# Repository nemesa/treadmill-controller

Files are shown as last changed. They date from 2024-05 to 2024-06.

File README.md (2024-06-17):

# treadmill-controller

## Try it in browser with a simulated arduino!
[Wokwi project](https://wokwi.com/projects/400015246220451841)

## Why is this project created?

I had two problems with my tredmill which I solved with a hardware button hack and an arudino uno.

[youtube video - during operation ](https://www.youtube.com/watch?v=EVUXpr3S0uo)

- Problem 1:
Speed setup

On my tredmill you can set an instant speed to 3, 6, 10, 16 Km/h and you can increase or decrase the speed by 0.1 Km/h, which sounds good until you want to run with the speed of 7.5 Km/h.  

In this case you have to set yout speed to 6 Km/h then increase your speed with 0.1 Km/h **15 times**!  
Like wise if you want to set speed to 4 km/h then you set your speed to 3 Km/h then increase your speed with 0.1 Km/h 10 times.
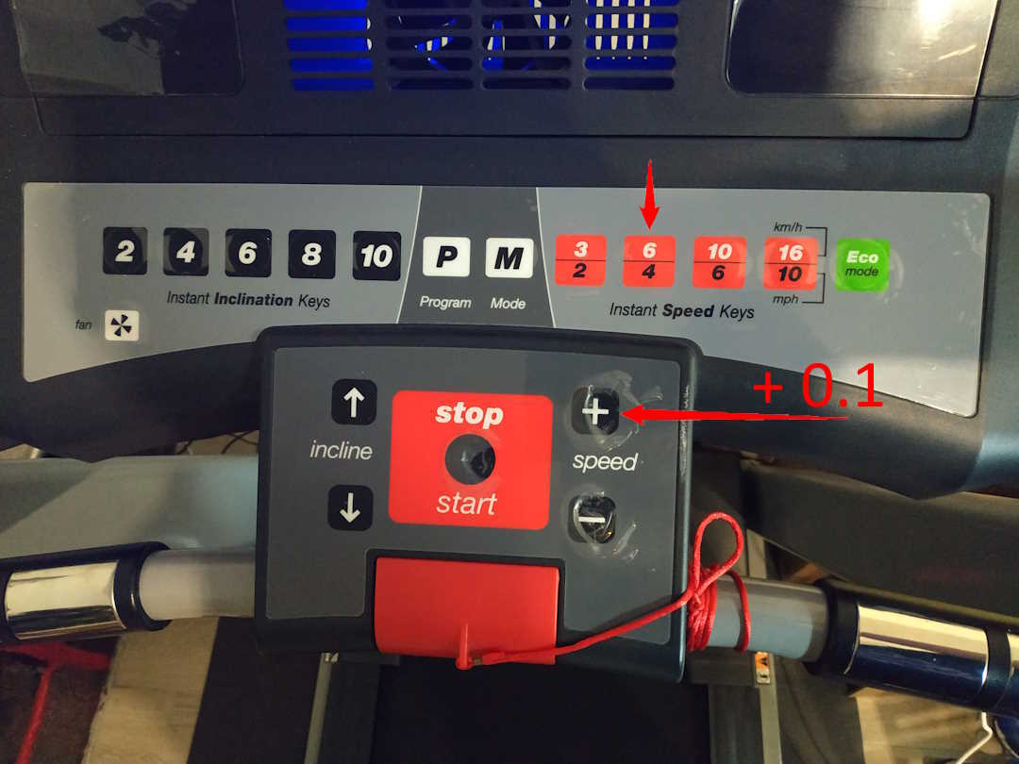
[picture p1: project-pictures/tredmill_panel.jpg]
tredmill_panel


- Problem 2:
Workout timeings

I usualy do intervall based trainings for example this one which trains you for a 5Km run race if you are newer did any runing before:

| week | workout code | workout day 1 |workout day 2 |workout day 3 |
|---|---|---|---|---|
| 1-2 | 2W&#124;[5&#124;1R&#124;2W] | 2 min walk -> 5X (1 min run -> 2 min walk) | same | rest |
| 3-4 | 2W&#124;[8&#124;1R&#124;1W]&#124;1W | 2walk -> 8X (1run, 1walk) -> 1walk | same | rest |
| 5 | 3W&#124;[4&#124;2R&#124;2W]&#124;1W | 3walk -> 4X (2run, 2walk) -> 1walk| same | same |
| 6 | 3W&#124;[5&#124;2R&#124;1W]&#124;1W | 3walk -> 5X (2run, 1walk) -> 1walk|rest | same |
| 7 | 4W&#124;[2&#124;2R&#124;1W&#124;3R&#124;2W] | 4walk -> 2X (2run, 1walk, 3run, 2walk)|rest | 45 min other workout |
| 8 | 4W&#124;[3&#124;3R&#124;2W]&#124;3W | 4walk -> 3X (3run, 2walk) -> 3walk| same | 45 min other workout |
| 9 | 4W&#124;[4&#124;3R&#124;1W]&#124;3W | 4walk -> 4X (3run, 2walk) -> 2walk| rest | rest |
| 10 | 5W&#124;[3&#124;4R&#124;2W]&#124;2W | 5walk -> 3X (4run, 2walk) -> 2walk| same | same |
| 11 | 5W&#124;[2&#124;5R&#124;2W]&#124;3R&#124;4W | 5walk -> 2X (5run, 2walk) -> 3run -> 4walk|same | 50 min other workout |
| 12 | 5W&#124;[2&#124;7R&#124;2W]&#124;2W | 5walk -> 2X (7run, 2walk) -> 2walk| rest | rest |
| 13 | 5W&#124;10R&#124;2W&#124;5R&#124;5W | 5walk -> 10run -> 2walk -> 5run -> 5walk|same | same |
| 14 | 5W&#124;15R&#124;6W | 5walk -> 15run -> 6walk | same | rest |
| 15 | 5W&#124;[4&#124;5R&#124;1W]&#124;2W | 5walk -> 4X (5run, 1walk) -> 2walk| rest | rest |
| 16 | 5W&#124;[3&#124;6R&#124;1W]&#124;4W | 5walk -> 3X (6run, 1walk) -> 4walk| same | same |
| 17 | 5W&#124;[3&#124;7R&#124;2W]&#124;4W | 5walk -> 3X (7run, 2walk) -> 4walk| same | same |
| 18 | 5W&#124;10R&#124;2W&#124;12R&#124;4W | 5walk -> 10run -> 2walk -> 12run -> 4walk | rest | rest |
| 19 | 5W&#124;[3&#124;9R&#124;1W] | 5walk -> 3X (9run, 1walk)| same | 60 min other workout |
| 20 | 5W&#124;15R&#124;2W&#124;[2&#124;5R&#124;2W] | 5walk -> 15run -> 2walk -> 2X (5run, 2walk)| same | same |
| 21 | 5W&#124;[3&#124;9R&#124;2W] | 5walk -> 3X (9run, 2walk)| same | same |
| 22 | 5W&#124;[3&#124;12R&#124;2W]&#124;4R&#124;4W | 5walk -> 3X (12run, 2walk) -> 4run -> 4walk| rest | 30 min other workout |
| 23 | 5W&#124;[3&#124;14R&#124;2W]&#124;2W | 5walk -> 3X (14run, 2walk) -> 2walk| rest | rest |
| 24 | 5W&#124;18R&#124;2W&#124;10R&#124;4W | 5walk -> 18run -> 2walk -> 10run -> 4walk  |same | 5 km race day |

So if we take week 3 which is a:  
2 min walk then 8X (1 min run then 1 min walk) then 1 min walk  
then would need to keep track of time and change between run and walk speed **18 times** and if you keep in mind the button press problem if you are an unfortunate invidual who walks at a speed of 4.5 Km/h and runs ant 7.5 Km/h then you will press buttons a woppin **15 x 18 = 270** times.  
This problem was screeaming for automation.

## Hardware button hack

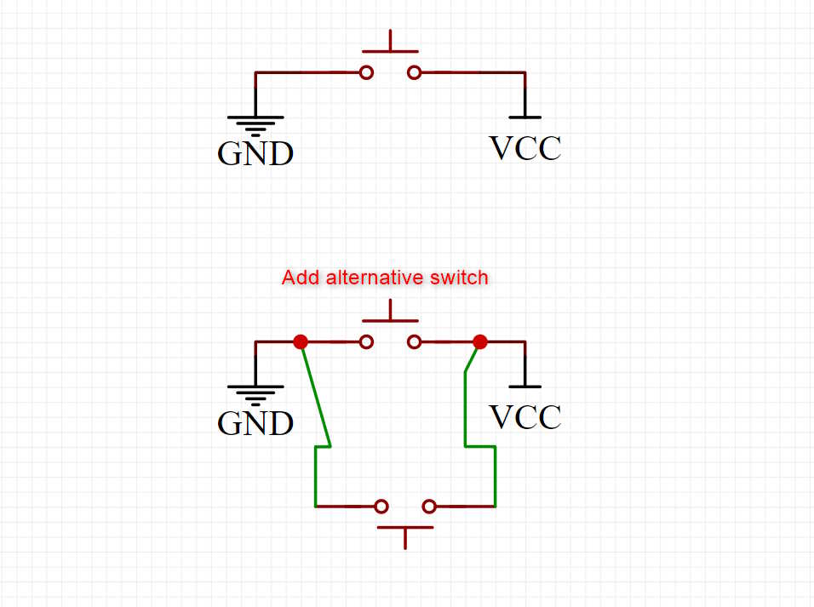
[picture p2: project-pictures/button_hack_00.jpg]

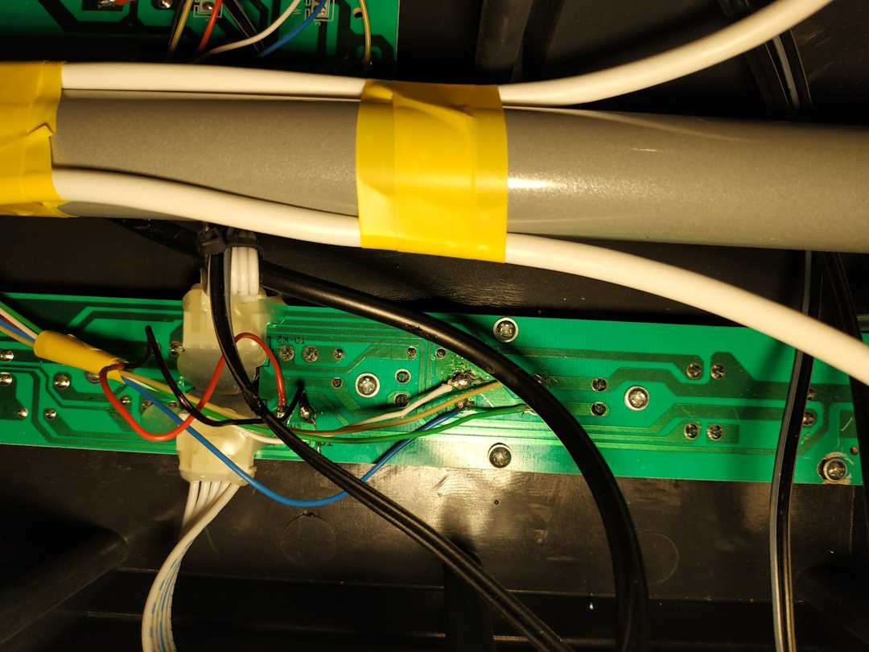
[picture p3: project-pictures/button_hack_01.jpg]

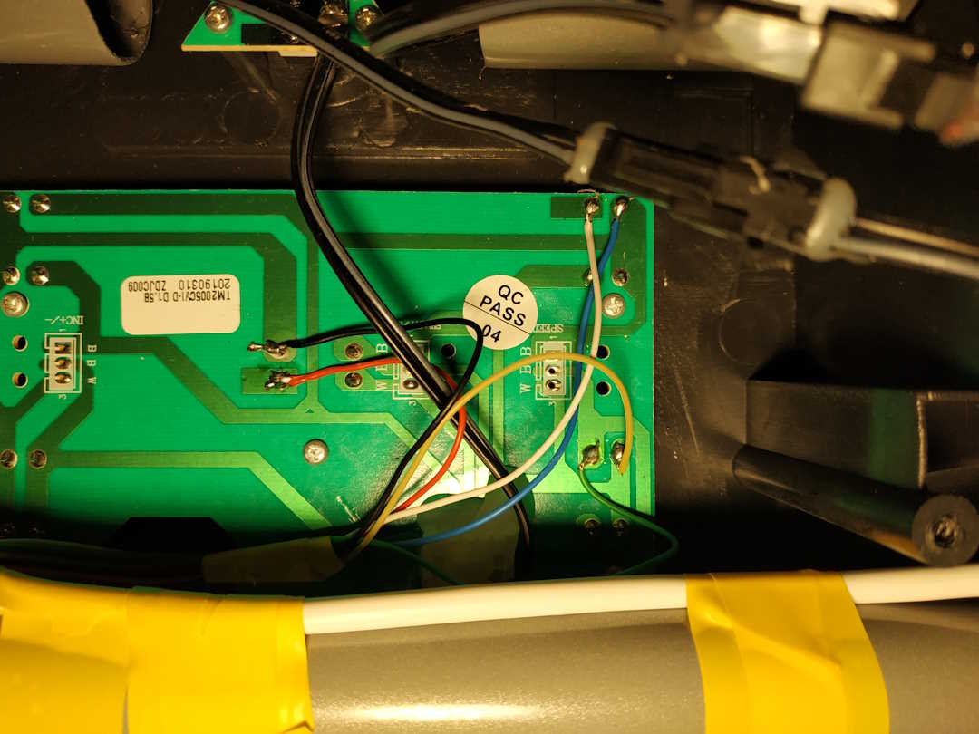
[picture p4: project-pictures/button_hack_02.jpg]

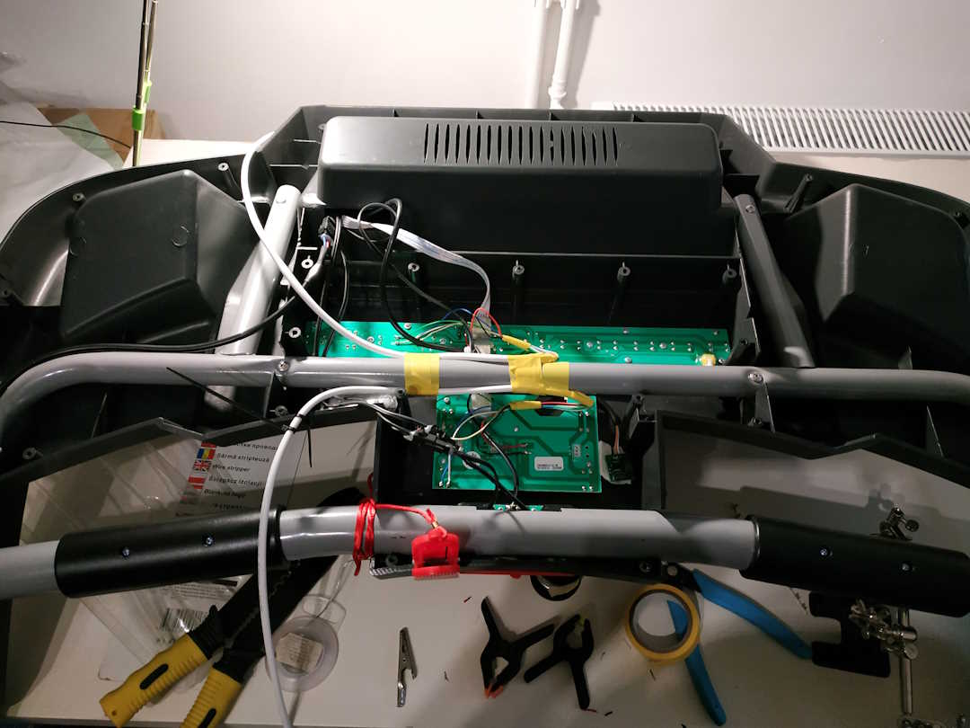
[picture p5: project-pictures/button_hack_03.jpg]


## Prototype

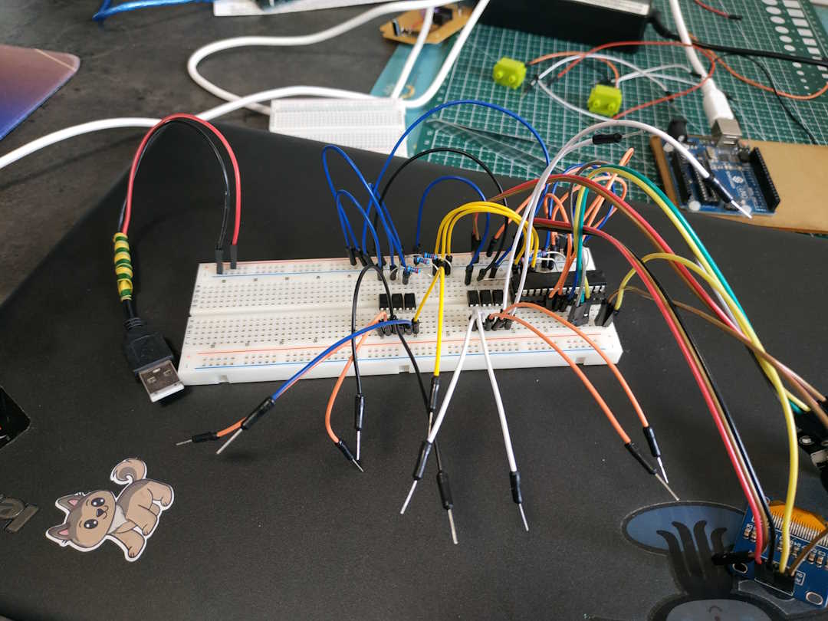
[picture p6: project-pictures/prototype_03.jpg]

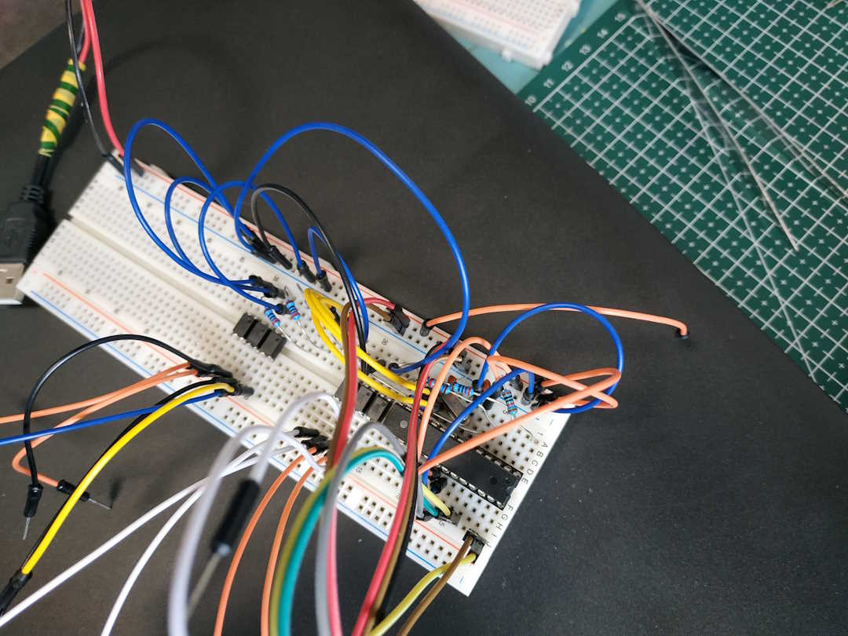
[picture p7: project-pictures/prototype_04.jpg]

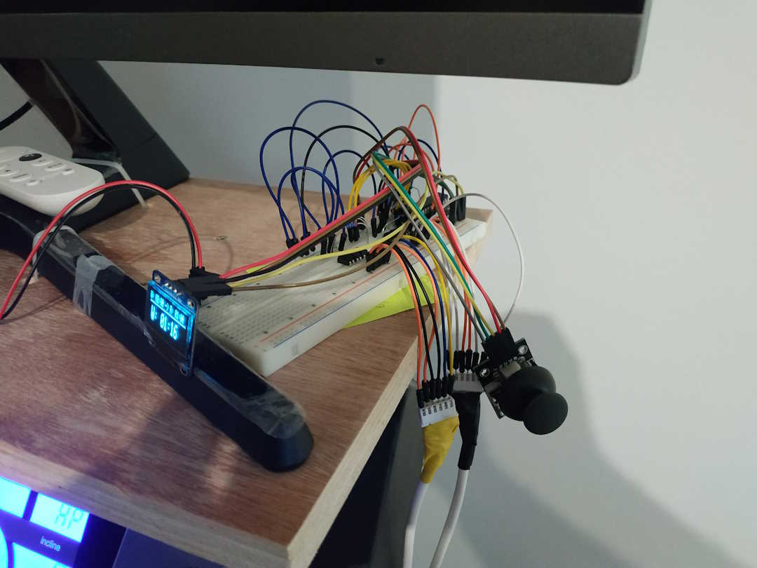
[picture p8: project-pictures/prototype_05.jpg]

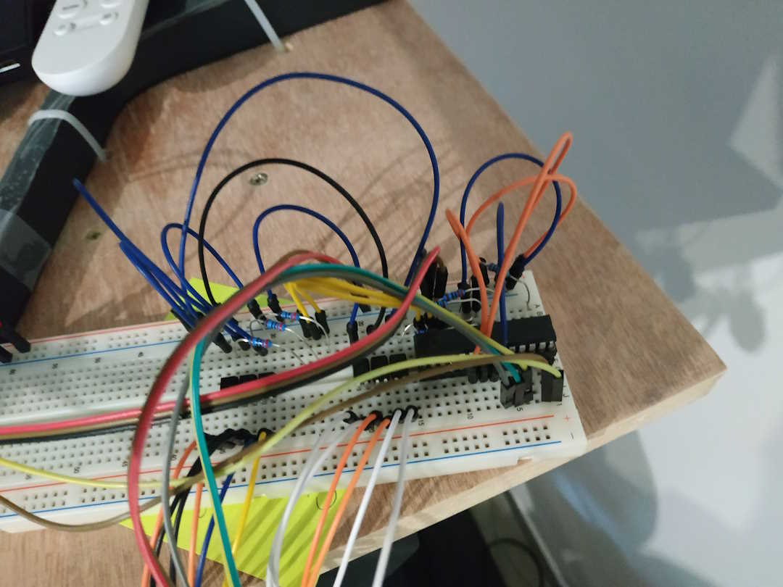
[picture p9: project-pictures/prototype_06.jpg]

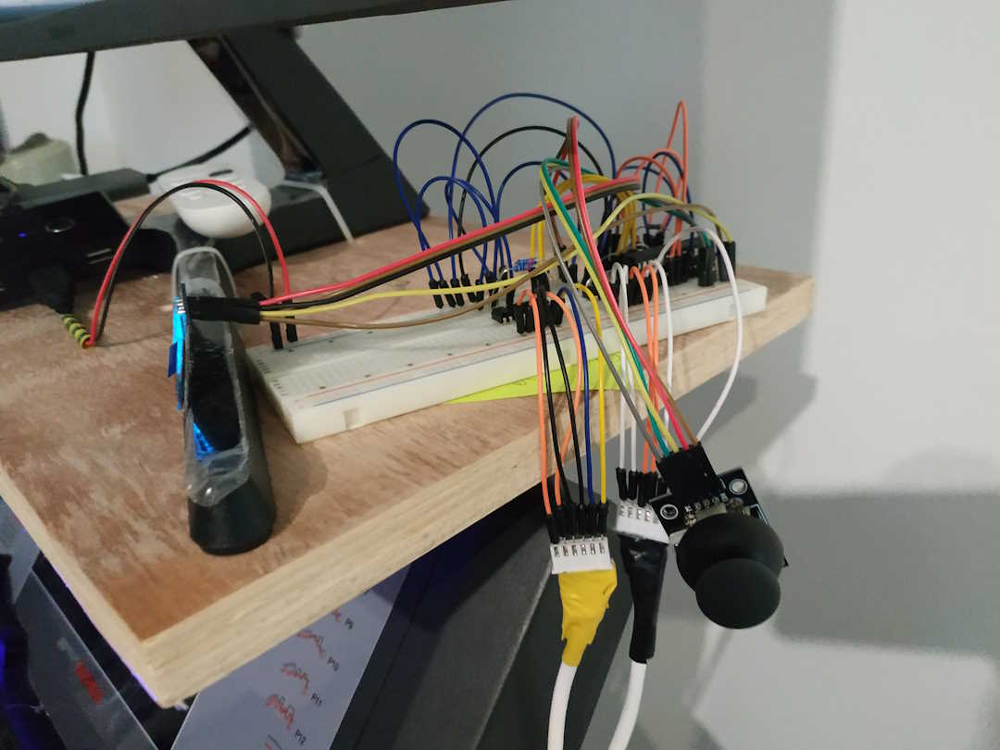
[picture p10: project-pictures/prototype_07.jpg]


## PCB

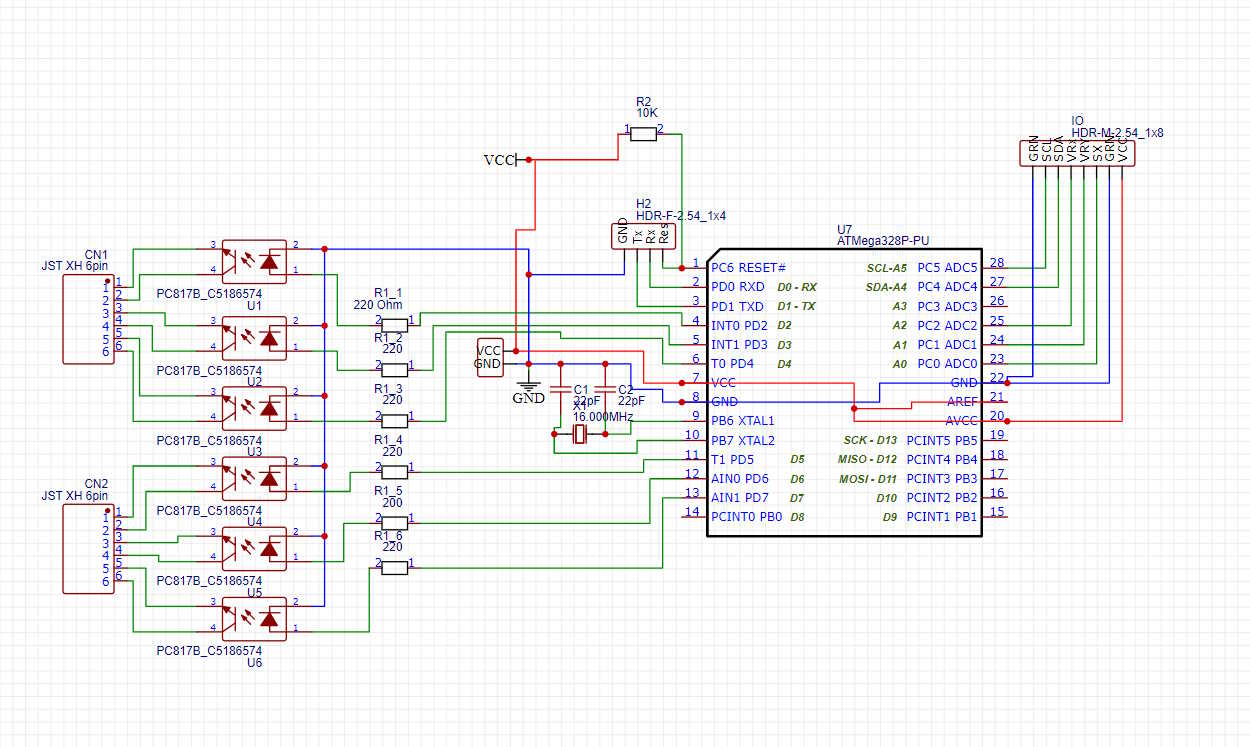
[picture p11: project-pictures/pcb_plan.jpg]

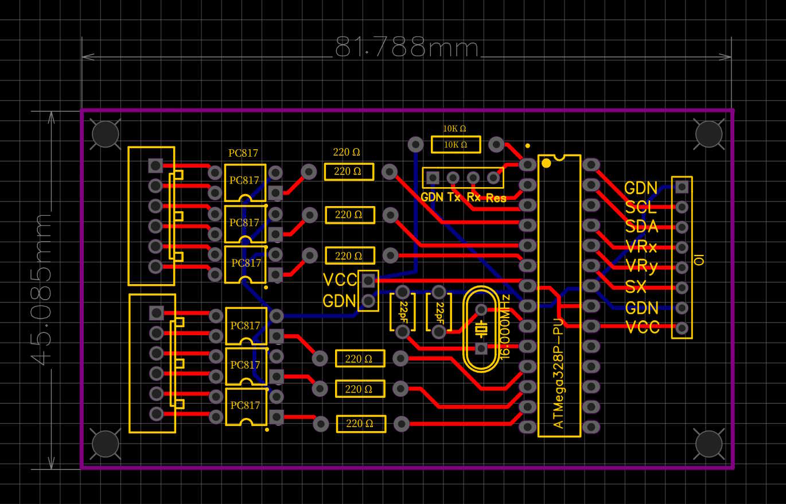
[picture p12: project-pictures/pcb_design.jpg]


## PCB finished

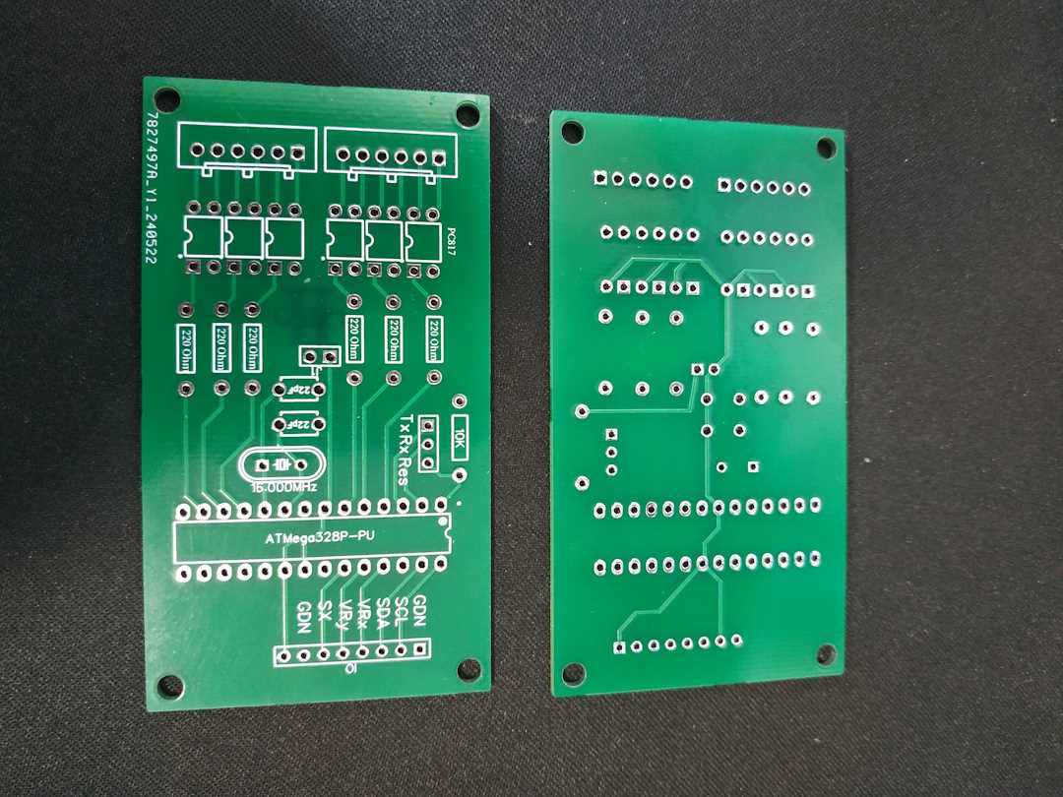
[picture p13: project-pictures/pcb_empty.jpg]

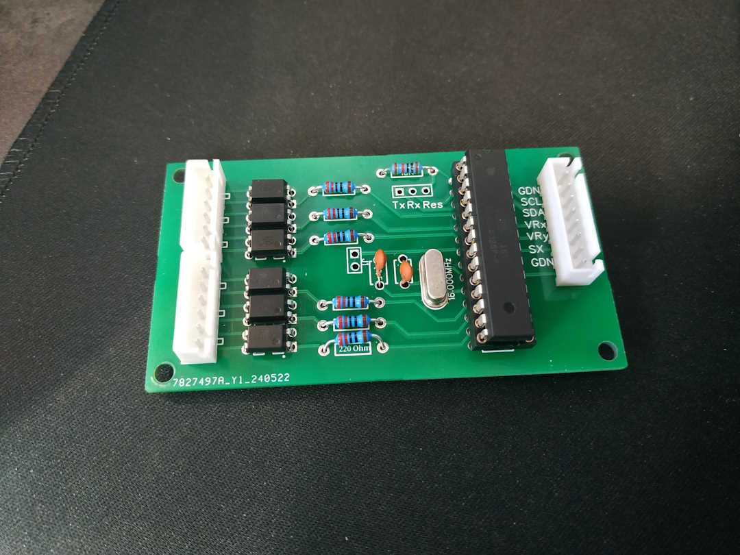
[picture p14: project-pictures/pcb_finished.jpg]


## Design the cover

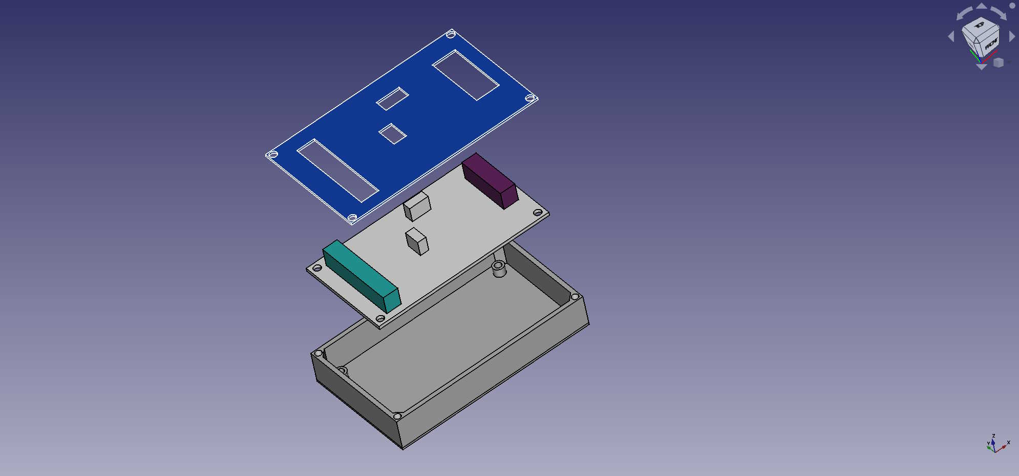
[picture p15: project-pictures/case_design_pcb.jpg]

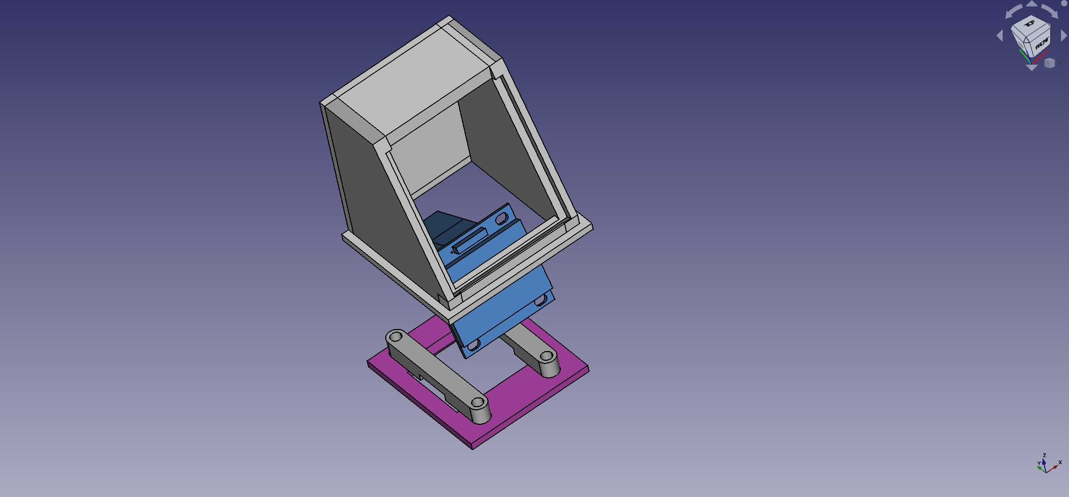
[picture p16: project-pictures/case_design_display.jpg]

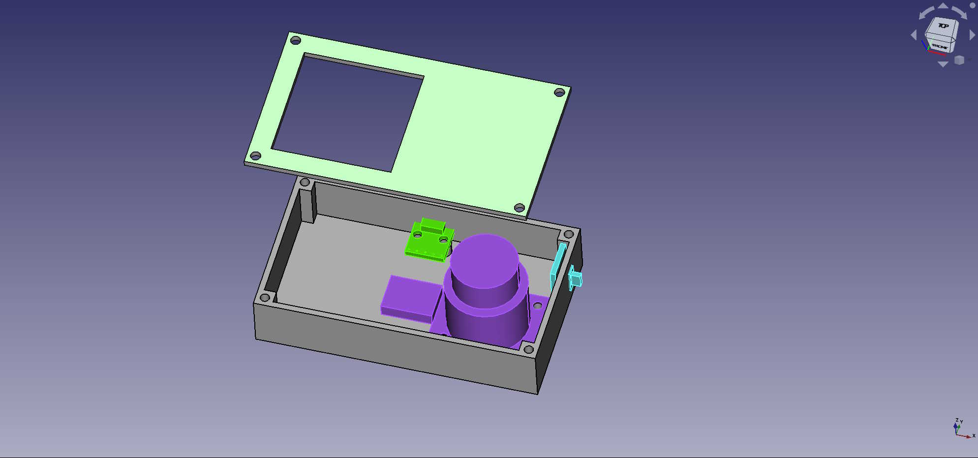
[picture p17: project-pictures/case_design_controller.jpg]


## Assembly

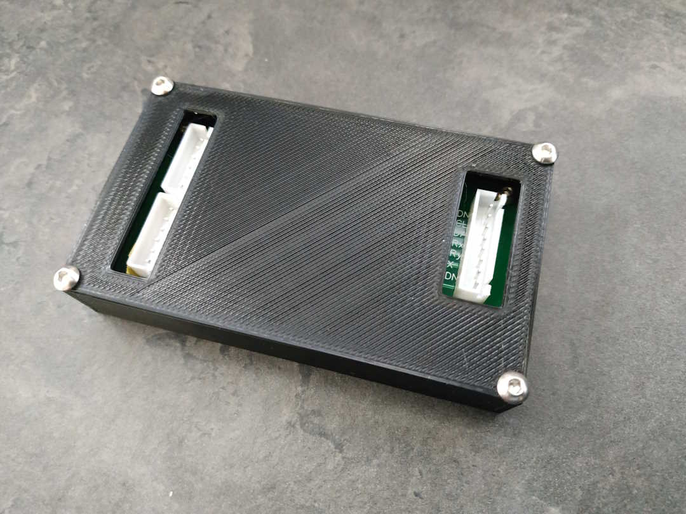
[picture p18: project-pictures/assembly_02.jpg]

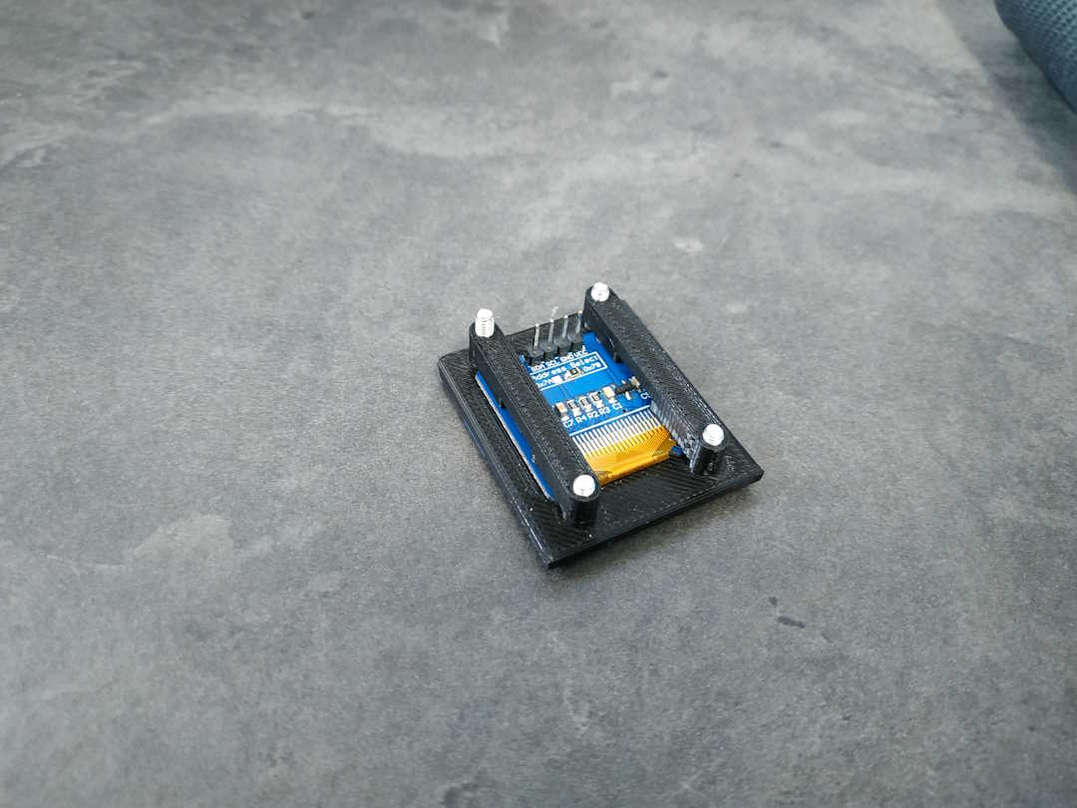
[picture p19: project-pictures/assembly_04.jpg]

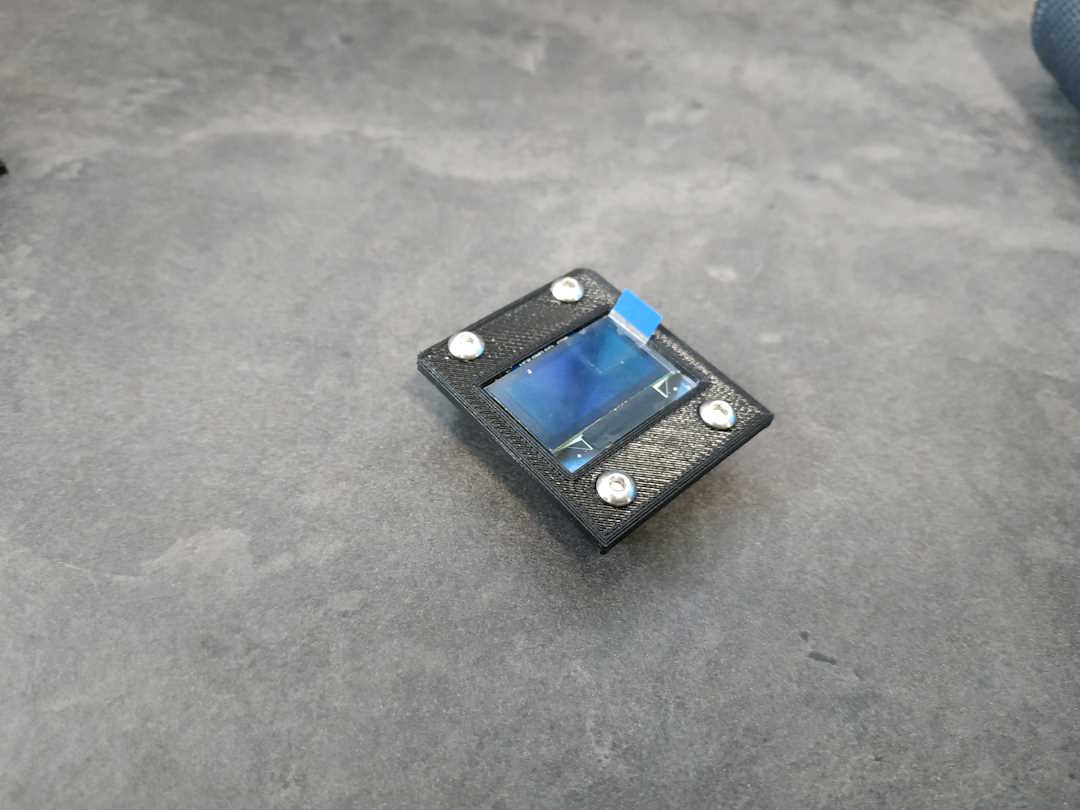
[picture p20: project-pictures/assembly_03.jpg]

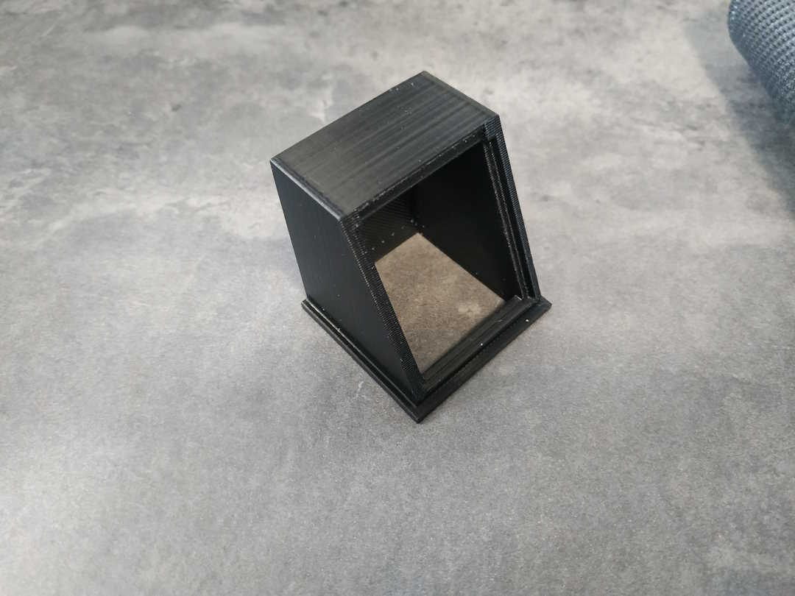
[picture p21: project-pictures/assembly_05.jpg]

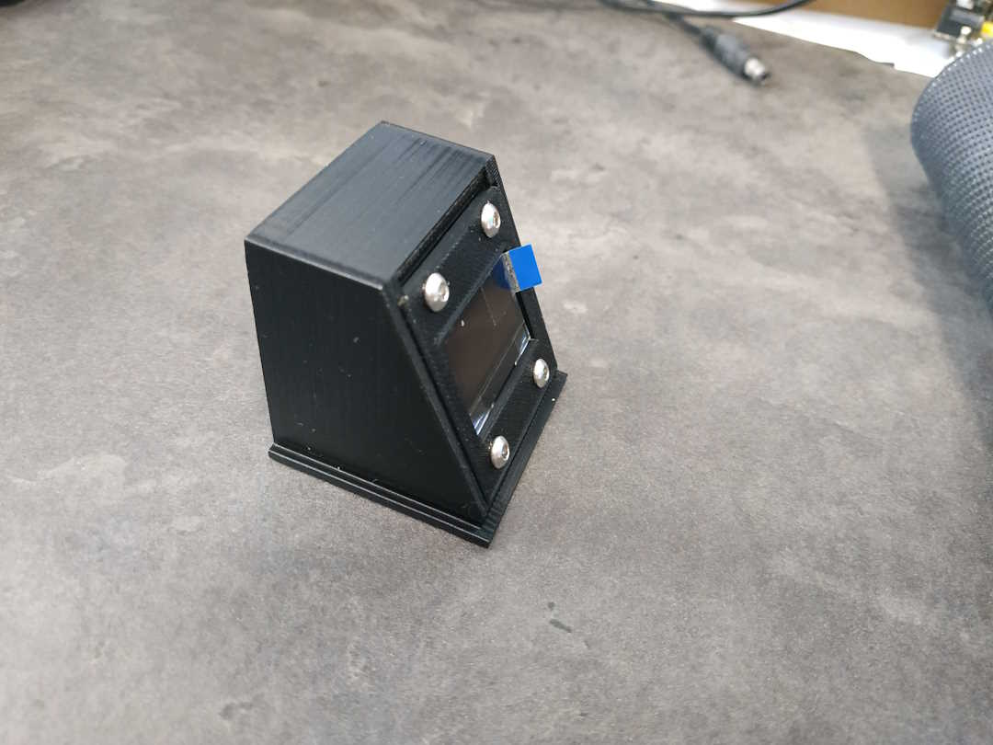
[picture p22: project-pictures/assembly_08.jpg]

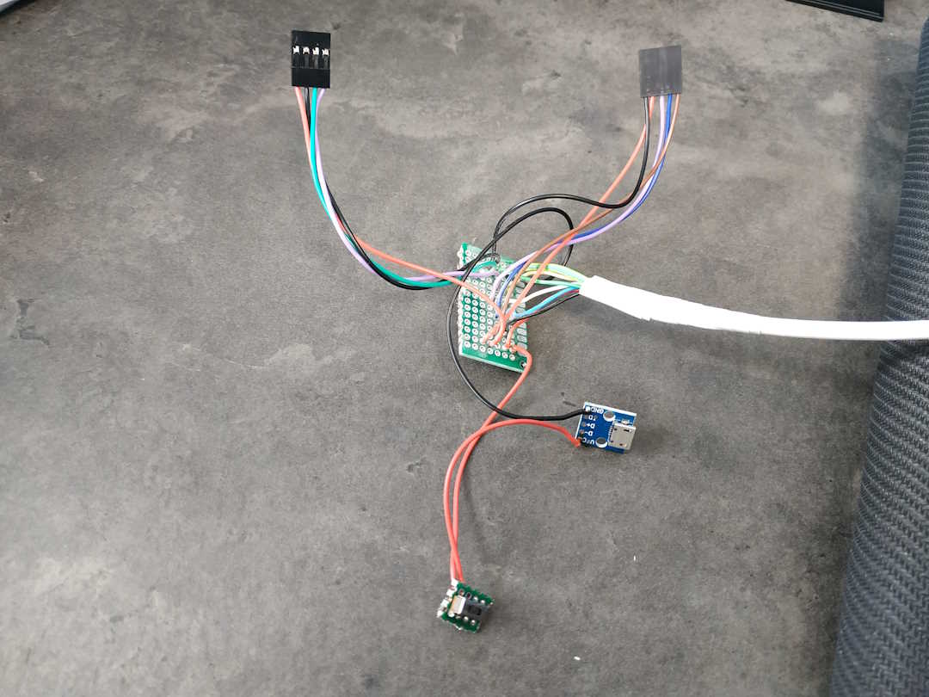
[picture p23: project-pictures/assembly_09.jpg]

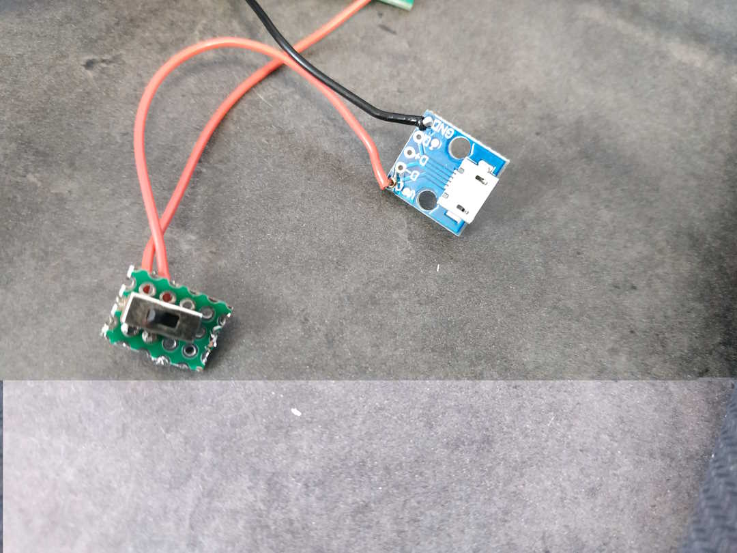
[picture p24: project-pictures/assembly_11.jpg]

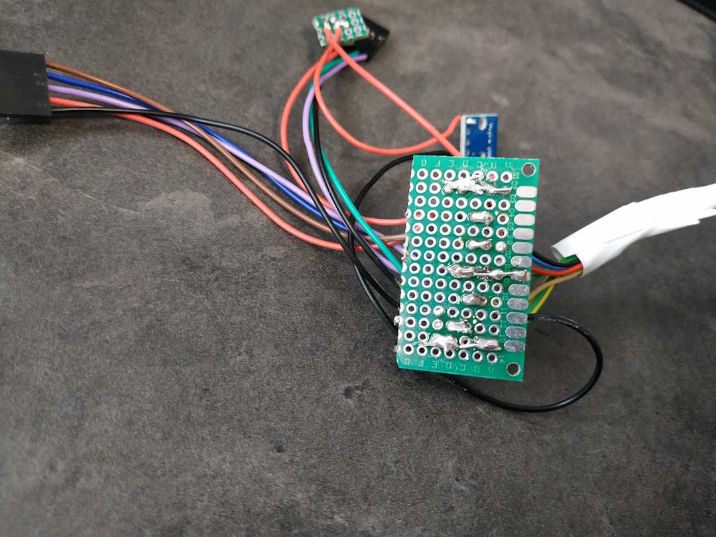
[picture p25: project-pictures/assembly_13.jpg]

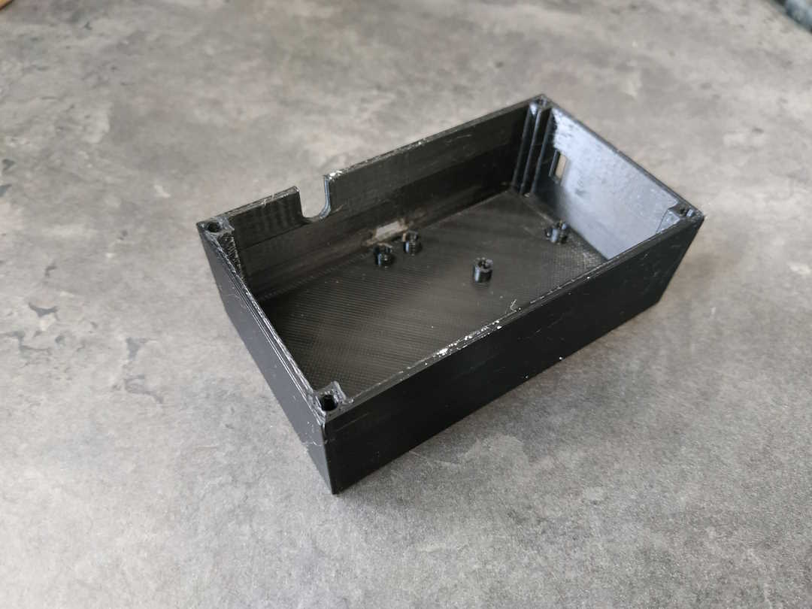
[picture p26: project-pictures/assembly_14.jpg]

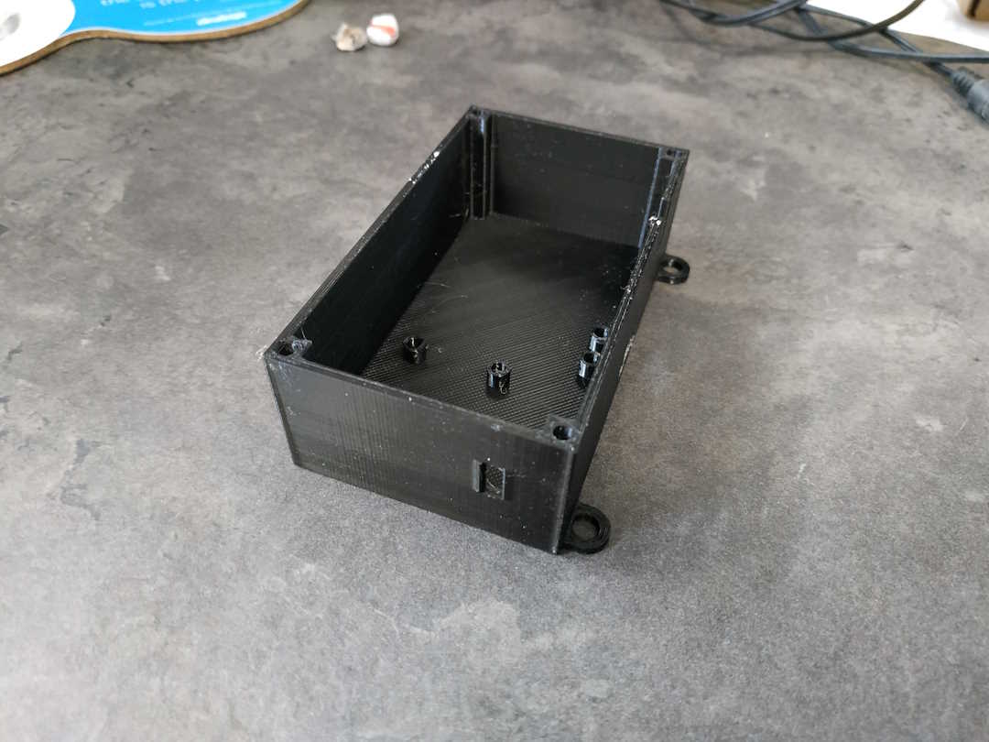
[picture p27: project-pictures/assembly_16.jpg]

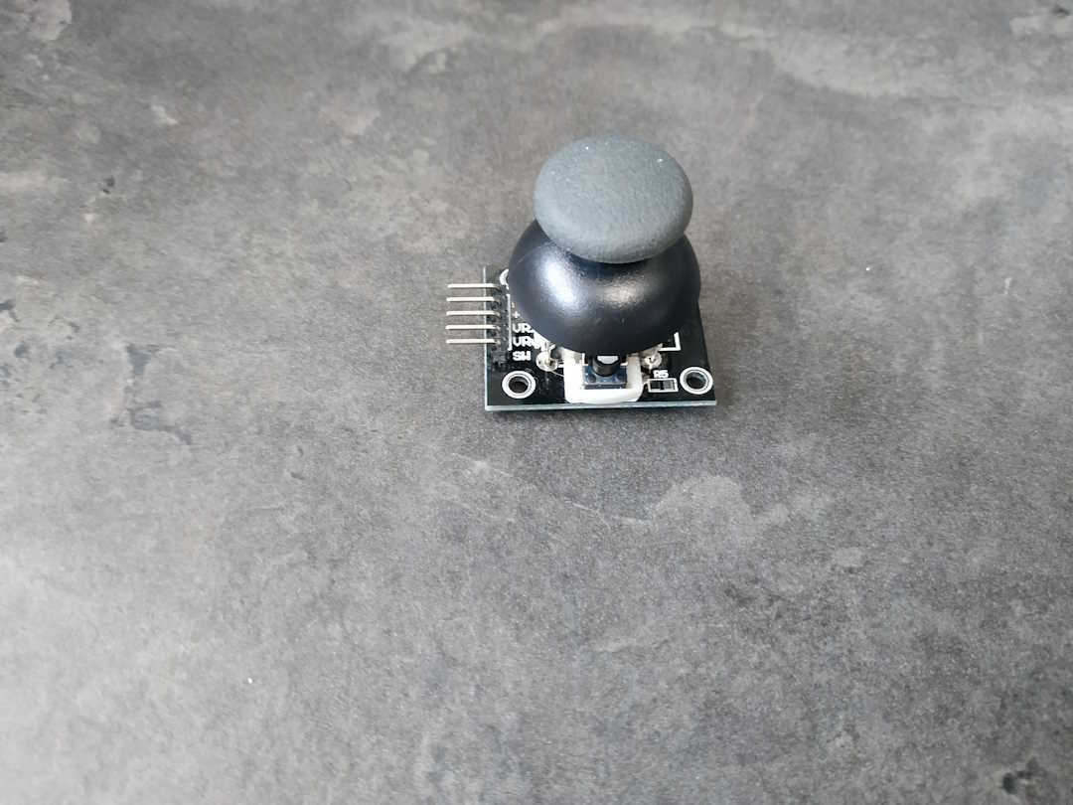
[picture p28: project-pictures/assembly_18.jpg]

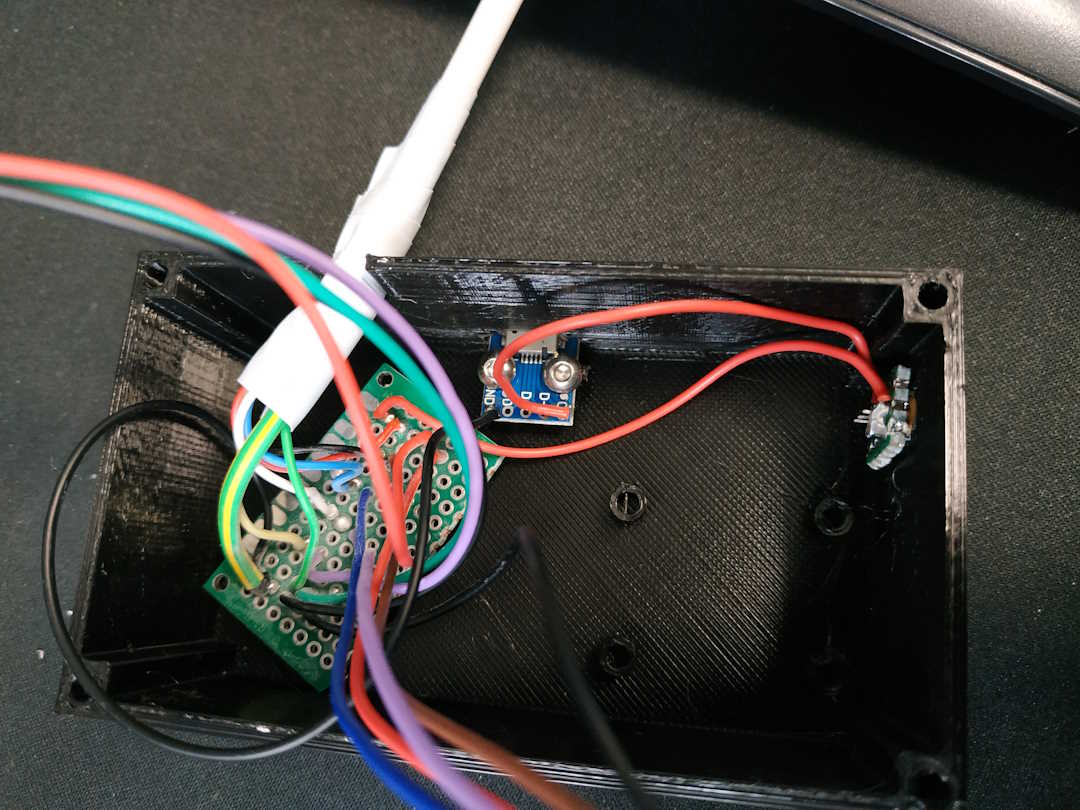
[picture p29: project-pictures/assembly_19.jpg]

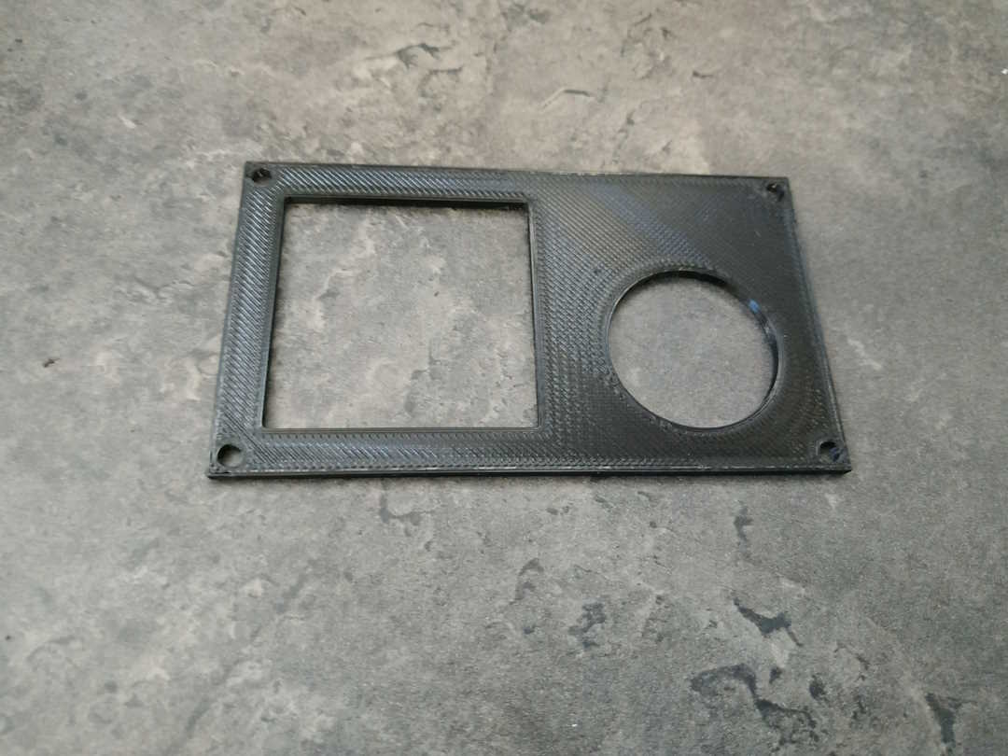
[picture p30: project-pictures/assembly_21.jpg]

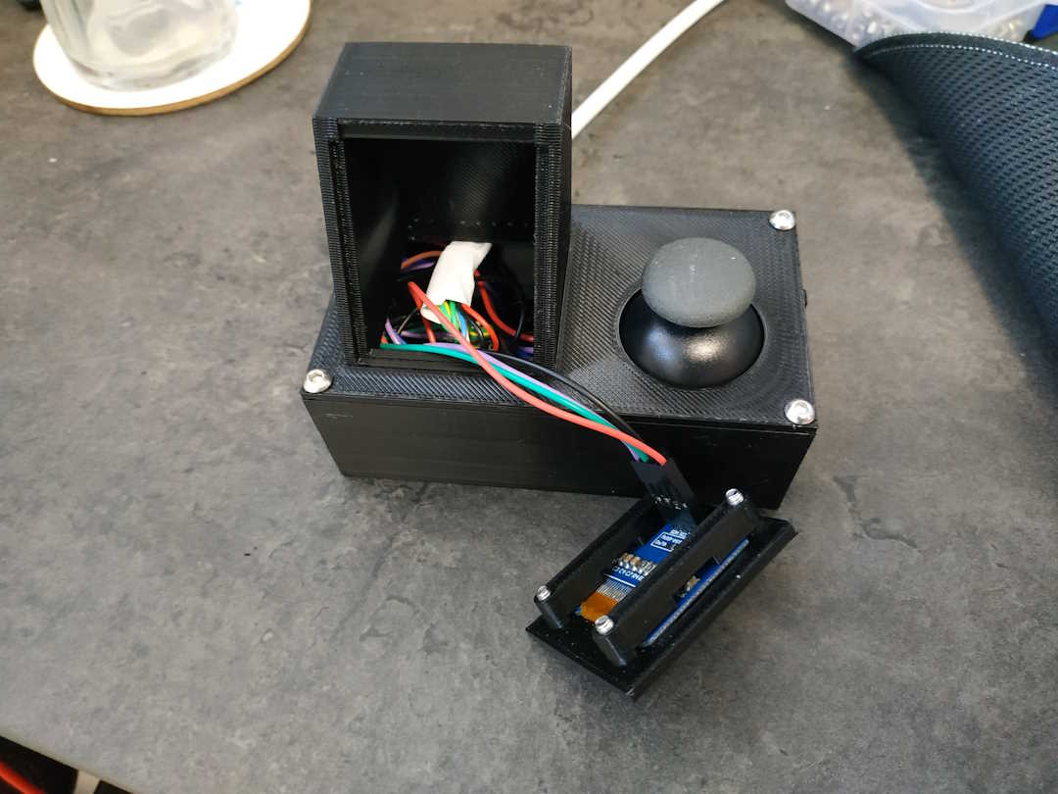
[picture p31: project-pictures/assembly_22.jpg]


## Finished case

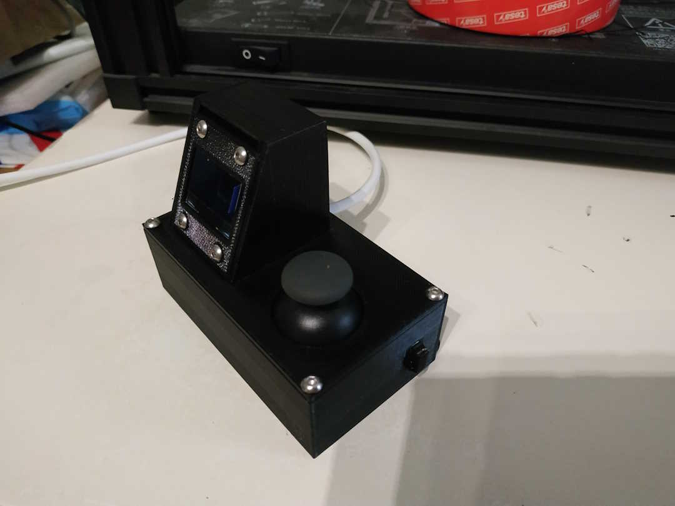
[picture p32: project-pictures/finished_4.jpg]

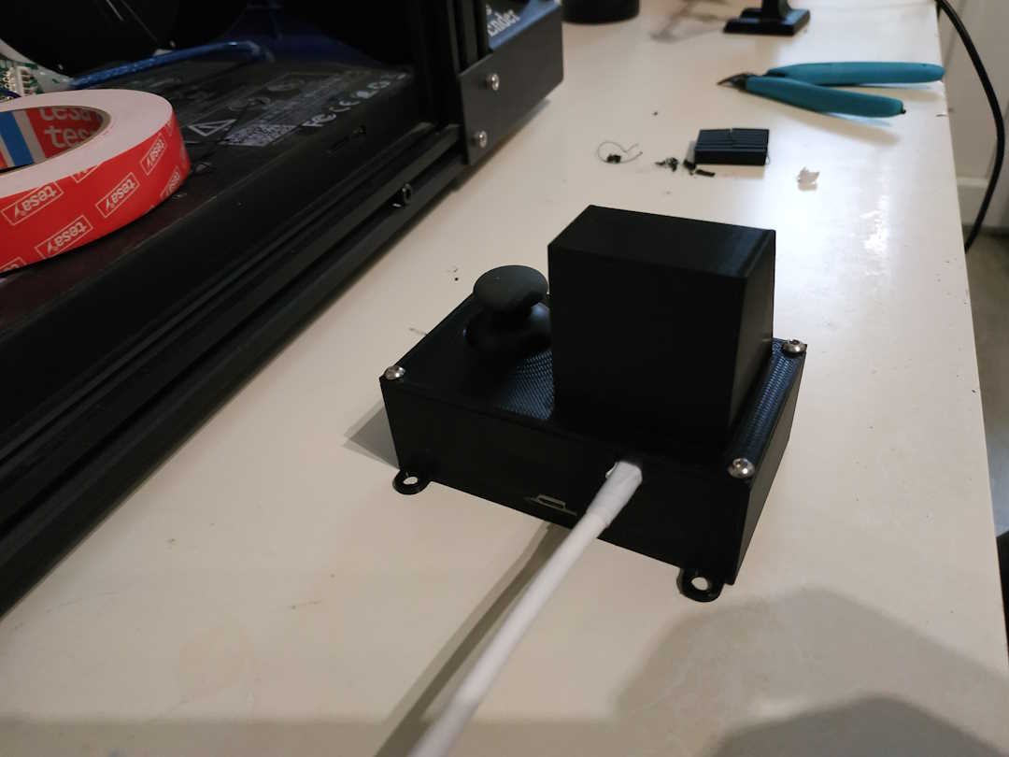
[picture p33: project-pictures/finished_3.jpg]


## What went wrong

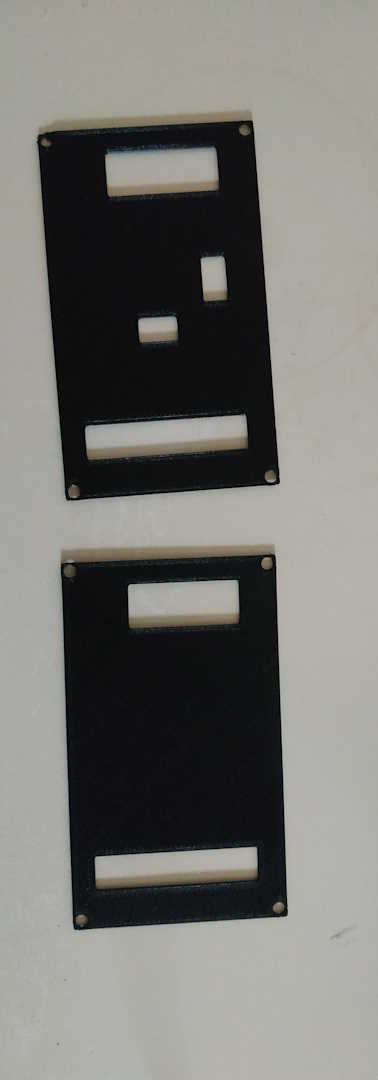
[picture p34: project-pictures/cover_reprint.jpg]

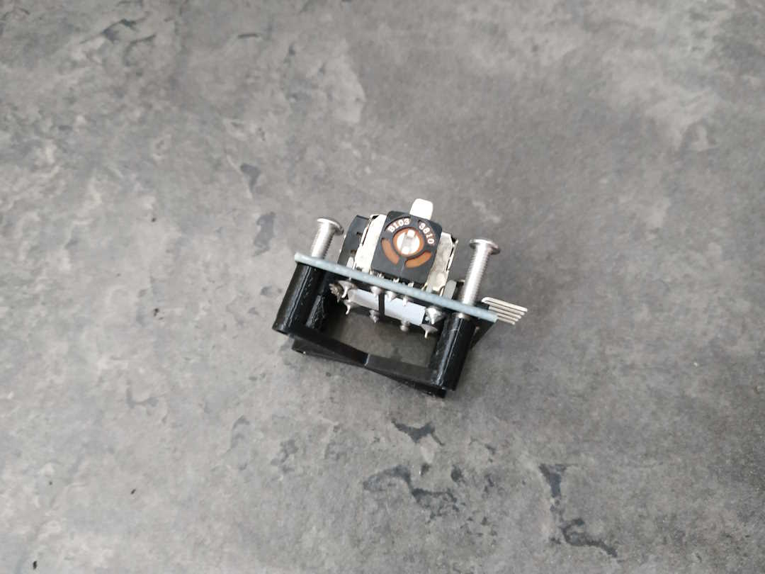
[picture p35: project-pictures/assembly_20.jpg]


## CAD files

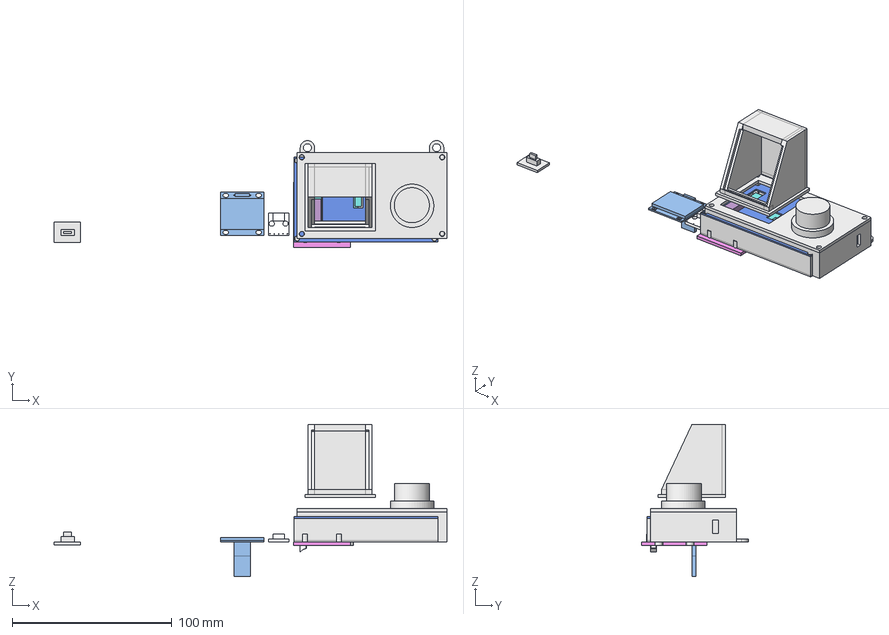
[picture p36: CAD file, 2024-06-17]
housing-cad/TredmillConrollerHousing_v5.FCStd
246.3 x 67.0 x 95.3 mm
Cut_ControllerCase_Top
Cut_DisplayCase
Cut_ControllerCase_Bottom
Cut_Toggle_Switch_Cover
Extrude_8pin_JST_XH_Sleeve
Extrude_6pin_JST_XH
Extrude_MainBoardCase_Top
Fusion_MicroUSBBreakout
Fusion__ContolleBoard
Fusion_diplayAndConnector
Fusion_Switch
Fusion_JoyStick_connector
Fusion_JoyBaseTest
Fusion_MicroUSBBreakoutBaseTest
Fusion_MainBoardCase_Bottom
Fusion_DisplayCase_Front
Fusion_DisplayCase_Mount

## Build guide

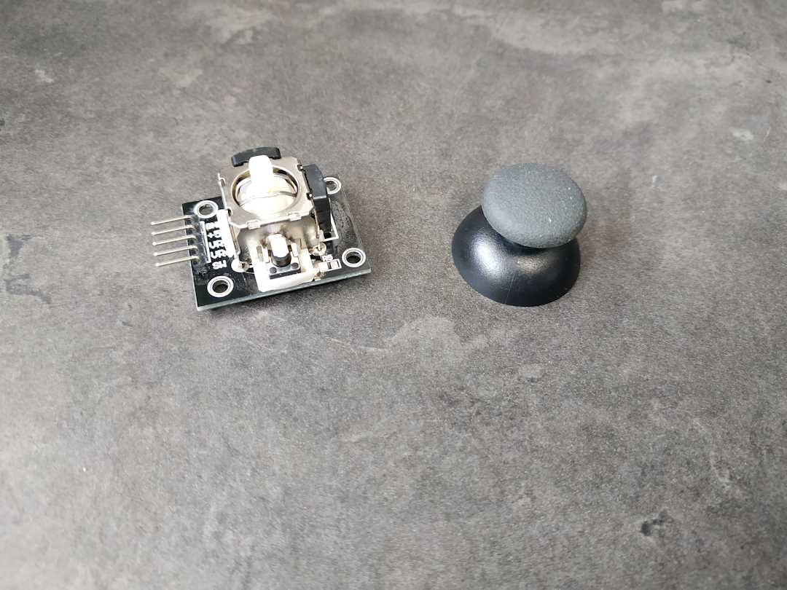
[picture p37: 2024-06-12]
project-pictures/assembly_17.jpg

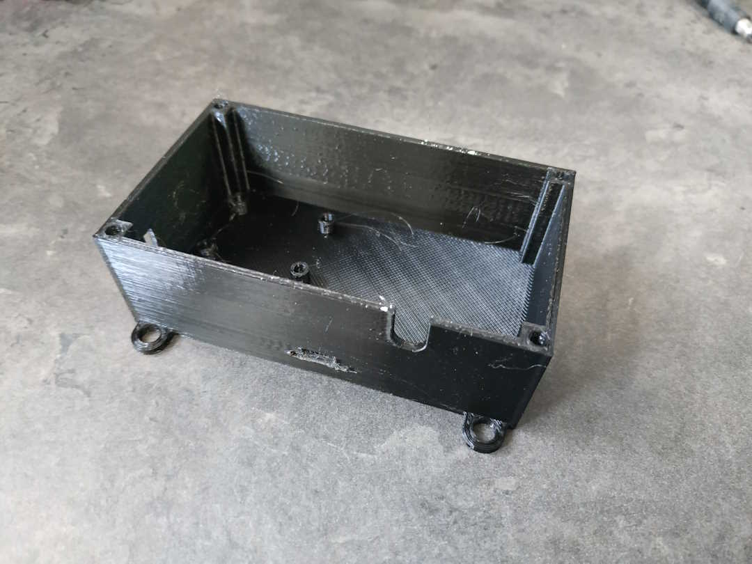
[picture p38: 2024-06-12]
project-pictures/assembly_15.jpg

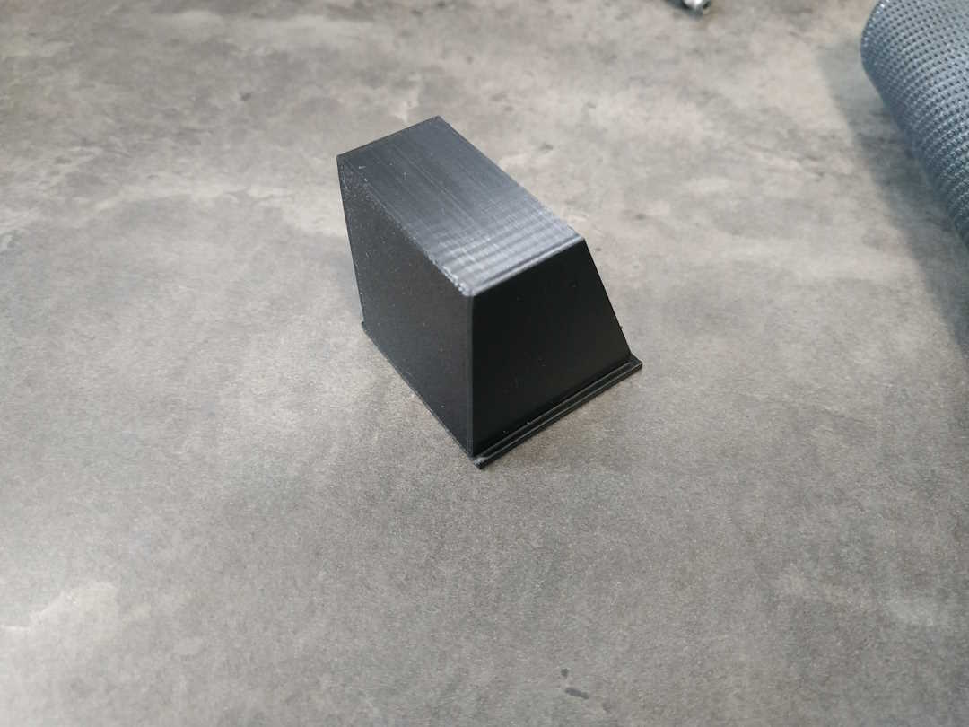
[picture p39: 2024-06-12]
project-pictures/assembly_06.jpg

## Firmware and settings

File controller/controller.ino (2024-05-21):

//I2C pins:
//SCL -> A5
//SDA -> A4

#define relayPin1 7
#define relayPin2 6
#define relayPin3 5
#define relayPin4 4
#define relayPin5 3
#define relayPin6 2

#define jSW A0
#define jY A1
#define jX A2


#include "joystick.h"
#include "menu.cpp"
#include "relay.h"
#include "eeprom.h"
#include "display.h"

JoystickHandler jh(jX, jY, jSW);
MenuHandler mh;
RelayHandler rh(relayPin1, relayPin2, relayPin3, relayPin4, relayPin5, relayPin6);
EEPROMHandler eh;
DisplayHandler dh;
struct JoystickState js;
bool inTimer = false;

void setup() {
  cli();  //stop interrupts

  TCCR1A = 0;  // set entire TCCR1A register to 0
  TCCR1B = 0;  // same for TCCR1B
  TCNT1 = 0;   //initialize counter value to 0
  // set compare match register for 1hz increments
  OCR1A = 15624;  // = (16*10^6) / (1*1024) - 1 (must be <65536)
  // turn on CTC mode
  TCCR1B |= (1 << WGM12);
  // Set CS10 and CS12 bits for 1024 prescaler
  TCCR1B |= (1 << CS12) | (1 << CS10);
  // enable timer compare interrupt
  TIMSK1 |= (1 << OCIE1A);

  sei();  //allow interrupts

  Serial.begin(115200);
  Serial.println(F("Setup"));
  rh.setup();
  eh.setup();
  jh.setup(&js);
  dh.setup();

  mh.setup(&eh, &rh, &dh);
}



void loop() {
  
  jh.loop(&js);
  if (js.isDownReleased) {
    mh.down();
  }
  if (js.isUpReleased) {
    mh.up();
  }
  if (js.isLeftReleased) {
    mh.left();
  }
  if (js.isRightReleased) {
    mh.right();
  }
  if (js.isSWReleased) {
    mh.select();
  }

  if (inTimer) {
    inTimer = false;
    mh.timerTick();
  }

  delay(10);
}


ISR(TIMER1_COMPA_vect) {  //timer1 interrupt 1Hz toggles pin 13 (LED)
                          //generates pulse wave of frequency 1Hz/2 = 0.5kHz (takes two cycles for full wave- toggle high then toggle low)
  inTimer = true;
}

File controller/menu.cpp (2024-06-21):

#include "Arduino.h"
#include "relay.h"
#include "eeprom.h"
#include "workout.cpp"
#include "display.h"

#define menuGlobalSettings 0

#define menuUserSelector 1

#define menuMain 2

#define menuWorkoutDetauls 3

#define menuOtherWorkouts 4

#define menuSettings 5

#define menuWorkout 6

class MenuHandler {
public:

  void setup(EEPROMHandler* eepromHAndler, RelayHandler* relayHandler, DisplayHandler* displayHandler) {
    Serial.println(F("MenuHandler-setup"));
    rh = relayHandler;
    eh = eepromHAndler;
    dh = displayHandler;
    user = eh->getLastSelectedUser();
    pinMap = eh->getControlPinMap();

    wh.setup();
    setUser(user.num);

    setMenu(menuUserSelector, -1, -1);
    //setMenu(menuWorkout, 1, -1);
  }
  void down() {
    if (menu == menuUserSelector) {
      readNextUser();
      dh->main(false, user.name);

    } else if (menu == menuMain) {
      subMenu = next(1, 3, subMenu, true, true);
      setMenu(menuMain, subMenu, 0);
    } else if (menu == menuOtherWorkouts) {
      subMenu = next(1, 29, subMenu, true, true);
      setMenu(menuOtherWorkouts, subMenu, 0);
    } else if (menu == menuSettings && subMenu < 10) {
      subMenu = next(1, 3, subMenu, true, true);
      setMenu(menuSettings, subMenu, 0);
    } else if (menu == menuGlobalSettings && subMenu < 10) {
      subMenu = next(4, 7, subMenu, true, true);
      setMenu(menuGlobalSettings, subMenu, 0);
    } else if (menu == menuSettings && subMenu == 10) {
      user.name[subMenu2] = (char)next(32, 122, user.name[subMenu2], true, true);
      setMenu(menuSettings, subMenu, subMenu2);
    } else if (menu == menuSettings && subMenu == 20) {
      walkSpeed = next(1, 160, walkSpeed, false, false);
      dh->main(false, getSpeed(walkSpeed));
    } else if (menu == menuSettings && subMenu == 30) {
      runSpeed = next(1, 160, runSpeed, false, false);
      dh->main(false, getSpeed(runSpeed));
    } else if (menu == menuGlobalSettings && subMenu > 40 && subMenu <= 49) {
      subMenu = next(41, 46, subMenu, true, true);
      setMenu(menuGlobalSettings, subMenu, 0);
    } else if (menu == menuGlobalSettings && subMenu > 50 && subMenu <= 59) {
      subMenu = next(51, 56, subMenu, true, true);
      setMenu(menuGlobalSettings, subMenu, 0);
    } else if (menu == menuGlobalSettings && subMenu == 60) {
      subMenu2 = next(1, 99, subMenu2, true, true);
      setMenu(menuGlobalSettings, subMenu, subMenu2);
    } else if (menu == menuGlobalSettings && subMenu == 70) {
      subMenu2 = next(1, 99, subMenu2, true, true);
      setMenu(menuGlobalSettings, subMenu, subMenu2);
    }
  }
  void up() {
    if (menu == menuUserSelector) {
      readPrevUser();
      dh->main(false, user.name);
    } else if (menu == menuMain) {
      subMenu = next(1, 3, subMenu, false, true);
      setMenu(menuMain, subMenu, 0);
    } else if (menu == menuOtherWorkouts) {
      subMenu = next(1, 29, subMenu, false, true);
      setMenu(menuOtherWorkouts, subMenu, 0);
    } else if (menu == menuSettings && subMenu < 10) {
      subMenu = next(1, 3, subMenu, false, true);
      setMenu(menuSettings, subMenu, 0);
    } else if (menu == menuGlobalSettings && subMenu < 10) {
      subMenu = next(4, 7, subMenu, false, true);
      setMenu(menuGlobalSettings, subMenu, 0);
    } else if (menu == menuSettings && subMenu == 10) {
      user.name[subMenu2] = (char)next(32, 122, user.name[subMenu2], false, true);
      setMenu(menuSettings, subMenu, subMenu2);
    } else if (menu == menuSettings && subMenu == 20) {
      walkSpeed = next(1, 160, walkSpeed, true, false);
      dh->main(false, getSpeed(walkSpeed));
    } else if (menu == menuSettings && subMenu == 30) {
      runSpeed = next(1, 160, runSpeed, true, false);
      dh->main(false, getSpeed(runSpeed));
    } else if (menu == menuGlobalSettings && subMenu > 40 && subMenu <= 49) {
      subMenu = next(41, 46, subMenu, false, true);
      setMenu(menuGlobalSettings, subMenu, 0);
    } else if (menu == menuGlobalSettings && subMenu > 50 && subMenu <= 59) {
      subMenu = next(51, 56, subMenu, false, true);
      setMenu(menuGlobalSettings, subMenu, 0);
    } else if (menu == menuGlobalSettings && subMenu == 60) {
      subMenu2 = next(1, 99, subMenu2, false, true);
      setMenu(menuGlobalSettings, subMenu, subMenu2);
    } else if (menu == menuGlobalSettings && subMenu == 70) {
      subMenu2 = next(1, 99, subMenu2, false, true);
      setMenu(menuGlobalSettings, subMenu, subMenu2);
    }
  }
  void left() {
    if (menu == menuUserSelector) {
      setMenu(menuGlobalSettings, 4, 0);
    } else if (menu == menuMain) {
      user = eh->getLastSelectedUser();
      setMenu(menuUserSelector, -1, -1);
    } else if (menu == menuWorkoutDetauls) {
      setMenu(menuMain, 1, 0);
    } else if (menu == menuOtherWorkouts) {
      setMenu(menuMain, 2, 0);
    } else if (menu == menuGlobalSettings) {
      if (subMenu > 40 && subMenu <= 49) {
        setMenu(menuGlobalSettings, 4, 0);
      } else if (subMenu > 50 && subMenu <= 59) {
        if (subMenu2 == 1) {
          setMenu(menuGlobalSettings, 5, 0);
        } else {
          subMenu2 = next(1, 6, subMenu2, false, true);
          setMenu(menuGlobalSettings, subMenu, subMenu2);
        }
      } else if (subMenu == 60) {
        setMenu(menuGlobalSettings, 6, 0);
      } else if (subMenu == 70) {
        setMenu(menuGlobalSettings, 7, 0);
      }
    } else if (menu == menuSettings) {
      if (subMenu < 10) {
        setMenu(menuMain, 3, 0);
      } else if (subMenu == 10) {
        if (subMenu2 == 0) {
          user = eh->getLastSelectedUser();
          setMenu(menuSettings, 1, 0);
        } else {
          subMenu2 = next(0, 6, subMenu2, false, true);
          setMenu(menuSettings, subMenu, subMenu2);
        }
      } else if (subMenu == 20) {
        setMenu(menuSettings, 2, 0);
      } else if (subMenu == 30) {
        setMenu(menuSettings, 3, 0);
      }
    } else if (menu == menuWorkout && (subMenu == 3 || subMenu == 1)) {
      setMenu(menuMain, 1, 0);
    }
  }
  void right() {
    if (menu == menuGlobalSettings && subMenu < 10) {
      user = eh->getLastSelectedUser();
      setMenu(menuUserSelector, -1, -1);
    } else if (menu == menuMain) {
      setMenu(menuWorkoutDetauls, -1, 0);
    } else if (menu == menuSettings && subMenu == 10) {
      subMenu2 = next(0, 6, subMenu2, true, true);
      setMenu(menuSettings, subMenu, subMenu2);
    } else if (menu == menuGlobalSettings && subMenu > 50 && subMenu <= 59) {
      subMenu2 = next(1, 6, subMenu2, true, true);
      setMenu(menuGlobalSettings, subMenu, subMenu2);
    }
  }
  void select() {
    if (menu == menuUserSelector) {
      eh->setLastUser(user.num);
      setMenu(menuMain, 1, 0);
    } else if (menu == menuMain && subMenu == 1) {
      setMenu(menuWorkout, 1, 0);
    } else if (menu == menuMain && subMenu == 2) {
      setMenu(menuOtherWorkouts, user.lastSelection, 0);
    } else if (menu == menuMain && subMenu == 3) {
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

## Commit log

2024-04-24 add led display
2024-05-09 timer interups with display
2024-05-18 Timer implementation pt1
2024-05-18 Timer implementation final
2024-05-18 add empty relay handler
2024-05-18 add empty relay handler pt2
2024-05-18 implement relay handler pt1
2024-05-19 relay handler - pin tester
2024-05-19 relay handler - pin map
2024-05-19 relay handler - toSpeed
2024-05-19 relay handler - tweek times
2024-05-21 change pin layout
2024-06-05 fix bug around eeprom handling
    [eeprom.cpp]
2024-06-12 Setup menu refactor (#2)
    * add glob setup with new button setup
    * fix missing user at load
    * fix user name edit
    [menu.cpp]
2024-06-17 add pictures and description
    [TredmillConrollerHousing_v5.FCStd]
2024-06-21 fix bug with name overwrite at speed setup and overflow at name setup
    [menu.cpp]
2024-07-16 fix bugs in workout setups
    [workout.cpp]
